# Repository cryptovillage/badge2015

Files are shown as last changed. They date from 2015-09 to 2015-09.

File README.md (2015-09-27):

# badge2015
Hardware, firmware, and documentation for the 2015 Crypto and Privacy Village Badge

# FAQs

Q: How do I build the firmware?

A: The firmware is built with Energia, an Arduino port for the MSP430. You will need to add
support for the MSP430G2955 to Energia. We used this "support pack:"
http://spirilis.net/junk/msp430/energia/g2955/energia13_g2955_spirilis_support.zip

Q: How are the flags/easter eggs hashed? 

A: Flags and easter eggs are hashed with a custom algorithm inspired by crypt(3). It uses about 3000
rounds of XXTEA cipher. The second-to-last round of XXTEA produces a key that is used to decrypt the
easter egg strings, which are themselves encrypted with XXTEA.

Q: Why 3000 rounds?

A: The number of rounds was chosen by observing how long the badge would take to validate a flag.
3000 rounds caused flag validation to take an amount of time just felt right. 3000 rounds also
makes brute-forcing the hashes infeasible, especially over a weekend. Remember, this hashing scheme
was not intended to be unbreakable -- just unbreakable over the weekend of DEF CON.

Q: Why are the genflag/genegg tools broken?

A: You need to compile them with -m32. The XXTEA code assumes 32-bit longs, but GCC uses 64-bit longs
on 64-bit architectures. Yes, I am aware this is easy to fix. Pull requests accepted!

Q: What's the story behind "Tetris mode?"

A: I wanted one of the challenges to involve a sidechannel attack. Unfortunately, if we wanted to
hide a secret on the MSP430, we'd have to blow the JTAG fuse, and we wanted to keep these badges as
hackable as possible. I also wanted to make a sidechannel challenge that did not require special
hardware. We were also somewhat constrained because the hardware had already been manufactured. I
knew that AM radios could pick up electromagnetic interference from digital devices, and everyone
at DEF CON probably had an AM radio in their hotel room. After a cursory search of the Internet, I 
found that someone had already implemented an AM transmitter by blinking an LED with an Atmel AVR!
We adapted their sample code, which played the "Tetris theme song."

Q: What's the unpopulated IC footprint on the badge for?

A: That is for a digital compass which was intended to be incorporated into the badge but dropped at
the last minute.

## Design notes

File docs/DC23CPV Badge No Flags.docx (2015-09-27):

# (U) DEF CON 23 Crypto And Privacy Village Badge Design Document

~~(U//FOUO)~~ This document contains the firmware specifications for the DEF CON 23 Crypto and Privacy Village Badge, including all behavior, flags, and easter eggs.

# (U) Testing

~~(U//FOUO)~~ When the badge is first powered up, it enters a self-test mode. All LEDs and segments on the display are lit for one second. After that, the badge cycles through all LEDs and segments individually. Pressing the left or right buttons cause an “L” or “R” to be displayed. Pressing both buttons simultaneously exits the self-test mode. The badge will not re-enter self-test mode without clearing the NVM.

# (U) Operation

## (U) Display Mode

~~(U//FOUO)~~ The badge is normally in “display mode,” which cycles through the words “DEFCON23,” “CRYPTO,” “AND,” “PRIVACY,” “VILLAGE.” There are 12 challenges to complete. The green LEDs corresponding to each challenge pulsate to indicate which challenges have been completed.

~~(C//REL)~~ If the Matrix easter egg is enabled, then the cycling of strings is slower. Part of the cycle time is used to resolve randomized characters to their actual characters. The random characters and resolution positions are generated by a 16-bit maximal LFSR. Any subset of the seven segments can be lit.

~~(C//REL)~~ If the LED1 easter egg is enabled, then the green LEDs randomly light every 250 milliseconds as chosen by a 16-bit maximal LFSR.

~~(C//REL)~~ If the LED2 easter egg is enabled, then the green LEDs perform a “walk.” LEDs start lighting up clockwise from the “walk” position until reaching the “walk” position, at which point the LEDs are extinguished clockwise until reaching the “walk” position again. The “walk” position then advances.

~~(C//REL)~~ If the Count easter egg is enabled, then the green LEDs count in binary, with the 12 o’clock position being the least-significant bit, and the 11 o’clock position being the most-significant bit.

~~(C//REL)~~ If the Pong easter egg is enabled, then the green LEDs perform a “pong” display. One LED advances slowly clockwise. Another LED advances either counter-clockwise or clockwise until it hits the slowly-advancing LED, at which point it reverses direction.

~~(C//REL)~~ If any easter egg messages are enabled, they will scroll after the “DEFCON23 CRYPTO AND PRIVACY VILLAGE” message is displayed.

~~(C//REL)~~ The preceding easter eggs are temporary and do not persist across power-cycles.

~~(C//REL)~~ If the EFF donor easter egg is activated, then users may cycle through a subset of the easter eggs (LED1, LED2, Pong, Matrix, and an “I fight for the users” message) by pressing the up button. The EFF donor flag persists across power-cycles but the easter egg enabled does not.

~~(TS//REL)~~ If all challenges are completed, the green LEDs randomly light every 50 milliseconds.

~~(TS//REL)~~ By pressing Up Up Down Down Up Down Up Down in “display mode,” the flag display mode can be entered which can be used to verify flags submitted.

## (U) Flag Entry Mode

~~(U//FOUO)~~ To enter the solution to a challenge (hereinafter referred to as a “flag”), press the right button in display mode. The green LEDs extinguish and the main display starts blinking an underscore to indicate that it is ready to accept an entry. Pressing the up and down buttons cycle through the characters of the current position, which blinks. An underscore indicates a space. Holding the down button for one second advances the character position. Advancing from the last position submits the flag for verification. Holding the up button for one second performs a backspace. Backspacing from the first position returns to “display mode.” Flags may also be submitted by pressing both buttons simultaneously. Empty spaces at the end of a flag will be converted to NULs before flag validation.

~~(U//FOUO)~~ Upon entry of a correct flag, the display will fade up the word “SUCCESS” and the corresponding green LEDs begins to pulsate. An animation of the other LEDs accents the newly lit LED. After five seconds, the badge reverts to “display mode.”

~~(C//REL)~~ Entry of any easter egg will activate that particular easter egg. Easter eggs are discussed below.

~~(C//REL)~~ Entry of a flag that is not a valid flag or easter egg will cause “LOL FAIL” to display for five seconds before reverting to “display mode.”

~~(S//REL)~~ Cycling through characters backwards through “A” will reveal 12 more non-unique characters, which light a corresponding green LED. These characters are used in a puzzle.

## ~~(~~~~S//REL)~~ Baudot/SSE Mode

~~(S//REL)~~ Upon entry to the Baudot mode, “LOOK IN TO MY EYES” scrolls across the display. Two sets of five green LEDs light in sequence to spell out characters using Baudot encoding. LEDs on the left side of the badge are the first, third, etc. characters, and LEDs on the right side of the badge are the second, fourth, etc. characters. Bits are ordered most-significant to least-significant from 11 o’clock to 1 o’clock.

## ~~(~~~~S//REL)~~ Tetris/RF mode

~~(S//REL)~~ Upon entry to Tetris mode, all LEDs and segments are extinguished except for the 3 o’clock LED, which stays lit. The 3 o’clock LED is modulated to provide music (commonly known as the “Tetris theme”) broadcast at 550 kHz using AM. At the end of this song, a message in Morse code is played at 15 WPM.

## ~~(C//REL)~~ Party/Rager mode

~~(C//REL)~~ After entering these easter eggs, the display scrolls “Are you sure?” followed by a display of “Y N.” If the left button is pressed (corresponding to Y), party mode is entered. If the right button is pressed, the badge goes back to “display mode.” If party mode is entered, a bit is set in NVM recording this fact. The duration of party mode (15 minutes for “party”, 60 minutes for “rager”) is also stored in NVM as a bit vector.

~~(C//REL)~~ In party mode, the green LEDs blink at 128 BPM. The LEDs are on for the duration of a sixteenth note at 128 BPM. The display scrolls “PARTY” back and forth, moving the position at 128 WPM. Party mode cannot be stopped. Every 60 seconds, the party duration counter is decremented in NVM. If the party duration reaches 0, the party bit in NVM is reset and the badge goes back to “display mode.”

## ~~(C//REL)~~ The “fuck” lockout

~~(C//REL)~~ If the word “fuck” is submitted as a flag, a bit is set in NVM indicating this fact. Display mode will not show anything but a series of dashes when this flag is set. Additionally, flag entry mode will not accept any flag except “sorry.” Other valid flags or easter eggs will cause “LOL FAIL” to be displayed. If “sorry” is submitted, the badge says “please don’t do it again,” clears the bit in NVM, and returns to display mode.

## ~~(C//REL)~~ Bullet time

~~(C//REL)~~ If the bullet time easter egg is entered, the display and LEDs are refreshed at a much slower interval (every 20 milliseconds).

## ~~(C//REL)~~ Resetting NVM

~~(C//REL)~~ The NVM can be completely erased by submitting “factoryr.” This will restore the self-test mode on the next power-cycle and clear all flags and other bits set.

# ~~(U//FOUO)~~ Flags

~~(S//REL)~~ Flags are “hashed” by through repeated encryptions by the XXTEA algorithm using the flag as the key. The initial input to XXTEA is 0x0000000000000001, and subsequent inputs are the outputs of previous iterations. Flags are hashed 3001 times. The output of the 3000th round is used as an XXTEA decryption key for easter egg messages.

~~(U//FOUO)~~ Flag list

~~(TS//REL)~~

12 o’clock | N
1 o’clock | NNE
2 o’clock | ENE
3 o’clock | E
4 o’clock | ESE
5 o’clock | SSE
6 o’clock | S
7 o’clock | SSW
8 o’clock | WSW
9 o’clock | W
10 o’clock | WNW
11 o’clock | NNW

~~(S//REL)~~ Puzzle mode enablers

SSE | SSE | Enters Baudot mode
NNW | TETRIS | Enters Tetris mode

# ~~(C//REL)~~ Easter Eggs

~~(C~~~~//REL)~~ Messages

HACK | “Drink all the booze hack all the things”
1337 | “got root”
CYBER | “GOVERNMENT MEDIA NOOB DRINK”
CYBER2 | “CYBER CYBER CYBER CYBER CYBER CYBER”
WBM | “FDHNER CRT VA N EBHAQ JBEYQ”
SUPERSAT | “HACKER EXTRAORDINARE”
JORGE | “The creator or dad”
GIBSON | “Hack the planet crash and burn”
ACIDBURN | “crash and burn”
ZEROCOOL | “mess with the best die like the rest”
JEFFMOSS | “ICANN PARTY”
TRAVIS | “FUCK YOU NEIGHBOR”
OSSMANN | “such radio much sniff wow”
GMARK | “don’t fuck it up”
NSA | “I C U P”
GOON | “HI PRIEST”
BEER | “take a drink”
HAD | “hackaday”
NINJA | “NINJA PARTY”
NEON | “LIZARD MOHAWKS FOR LIFE”
DIFFIE | “I love discrete logs”
HELLMAN | “Watch out for Mallory”
1o57 | “e ahzojr nrjx qbr Amfx, qyeyxs ume xev myfpxpnxffr”
DEFCON | “canceled next year”
DEFCOIN | “cash rules everything around me”
ALICE | “bit ly alicenbob”
BOB | “Alice is sending her message to Bob Protecting that transmission is crypto’s job”
EVE | “Eve is jealous of Alice”
ROT13 | “So secure”
OPENSSL | “Open Season”
EFF | “Fighting for the users”
DARTHNULL | YGcpeevgCIKgfnMwefXzvGUHe3BgQKdxkMFeappqmVT0cNOkvGY6ehfo”
WARGAMES | “Shall we play a game”
SNEAKERS | “The world isn’t by weapons anymore or energy or money its run by little ones and zeros little bits of data Its all just electrons.”
SETEC | “Too many secrets marty”
LOTR | “Keep it secret keep it safe”
SCORPION | “250 years of bullshit er human thought every 90 minutes”

~~(C//REL)~~ Other easter eggs

MATRIX | Enables Matrix Mode
FUCK | Enables the “fuck” lockout
LED1 | Enables LED1 easter egg
LED2 | Enables LED2 easter egg
PONG | Enables PONG easter egg
COUNT | Enables Count easter egg
PARTY | Enables 15 minute party mode
RAGER | Enables 60 minute party mode
SORRY | Removes the “fuck” lockout
3FFD0N0R | Says “thank you for supporting the EFF” and set the EFF supporter bit
OVERCLOK | Sets ledMaxBrightness to 0xff (already 0xff on final firmware)
BULLETYM | Enables bullet time easter egg
FACTORYR | Performs a full erase of the NVM

[Type text][Type text][Type text]

~~TOP SECRET//DEFCON//REL TO 4EYES~~

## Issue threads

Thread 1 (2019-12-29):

re-programming

gigawatts, 2019-12-29:
I was looking to explore re-purposing / programming this badge, and I am looking for a pin-out for the programming header on the badge, along with some tips on a procedure.

Is it using this pinout? https://www.olimex.com/Products/MSP430/_resources/msp430-jtag.gif

I saw the "CONN_01x14 / P1" connector in the schematic PDF, but it only labels 4 pins. Are the rest not connected to the MSP430?

Do you have some notes on a process to re-flash this? My only other MSP experience is on a Stellaris LaunchPad (with Energia), but that was easily re-programmed with just USB. I have a few other programmers available, including a buspirate and Black Magic Probe clone.

Any hints would be appreciated!

supersat, 2019-12-29:
You are correct that only 4 pins on the programming header are connected to the MSP430. We debugged and programmed them using TI's Spy-Bi-Wire protocol instead of JTAG, which only requires those four pins.

The firmware was originally developed with a MSP-EXP430G2 LaunchPad, although the production badges have a larger microcontroller (MSP430G2955 vs MSP430G2744) that is not supported by it. Apparently newer LaunchPads might support it?

gigawatts, 2019-12-30:
Giving it a shot with my Stellaris LM4F120 (removing the jumper that powers the onboard micro.

Next issue, I downloaded the support pack you linked to, and based on its name, downloaded the old Energia 0101E0013 version, selected the "Spirilis' G2955 LaunchPad" board option, but every upload attempt just errors with "No unused FET found." What version of Energia did you use with that support pack?

I'm pretty sure I have all the right drivers installed, as I can upload sketches to the onboard lm4f120 micro just fine from Energia (selecting the lm4f120 board, of course).

gigawatts, 2020-01-07:
I gave up on the Stellaris, pretty sure it does not support SBW. I picked up a cheap LaunchPad MSP-EXP430G2. I was able to program it's onboard G2553 with Energia v13 without any issues. I removed the jumpers, then connected GND, VCC, RST, and TEST over to the badge.

Attempting to upload (after picking Board "Spirilis' G2955 LaunchPad"), I just get this error now:
```
tilib: MSP430_OpenDevice: Could not find device (or device not supported) (error = 4)
tilib: device initialization failed
```

Any ideas?

supersat, 2020-01-07:
The MSP-EXP430G2 explicitly does not support the G2955 (see my comment above). However, if you were to remove the G2955 and replace it with a G2744, it would be pin-compatible and work just fine.

That being said, it's probably easier to find a compatible programmer.

gigawatts, 2020-01-07:
Doh, then I misunderstood your previous statement about chip support. Which LaunchPad or programmer will work, without spending too much?

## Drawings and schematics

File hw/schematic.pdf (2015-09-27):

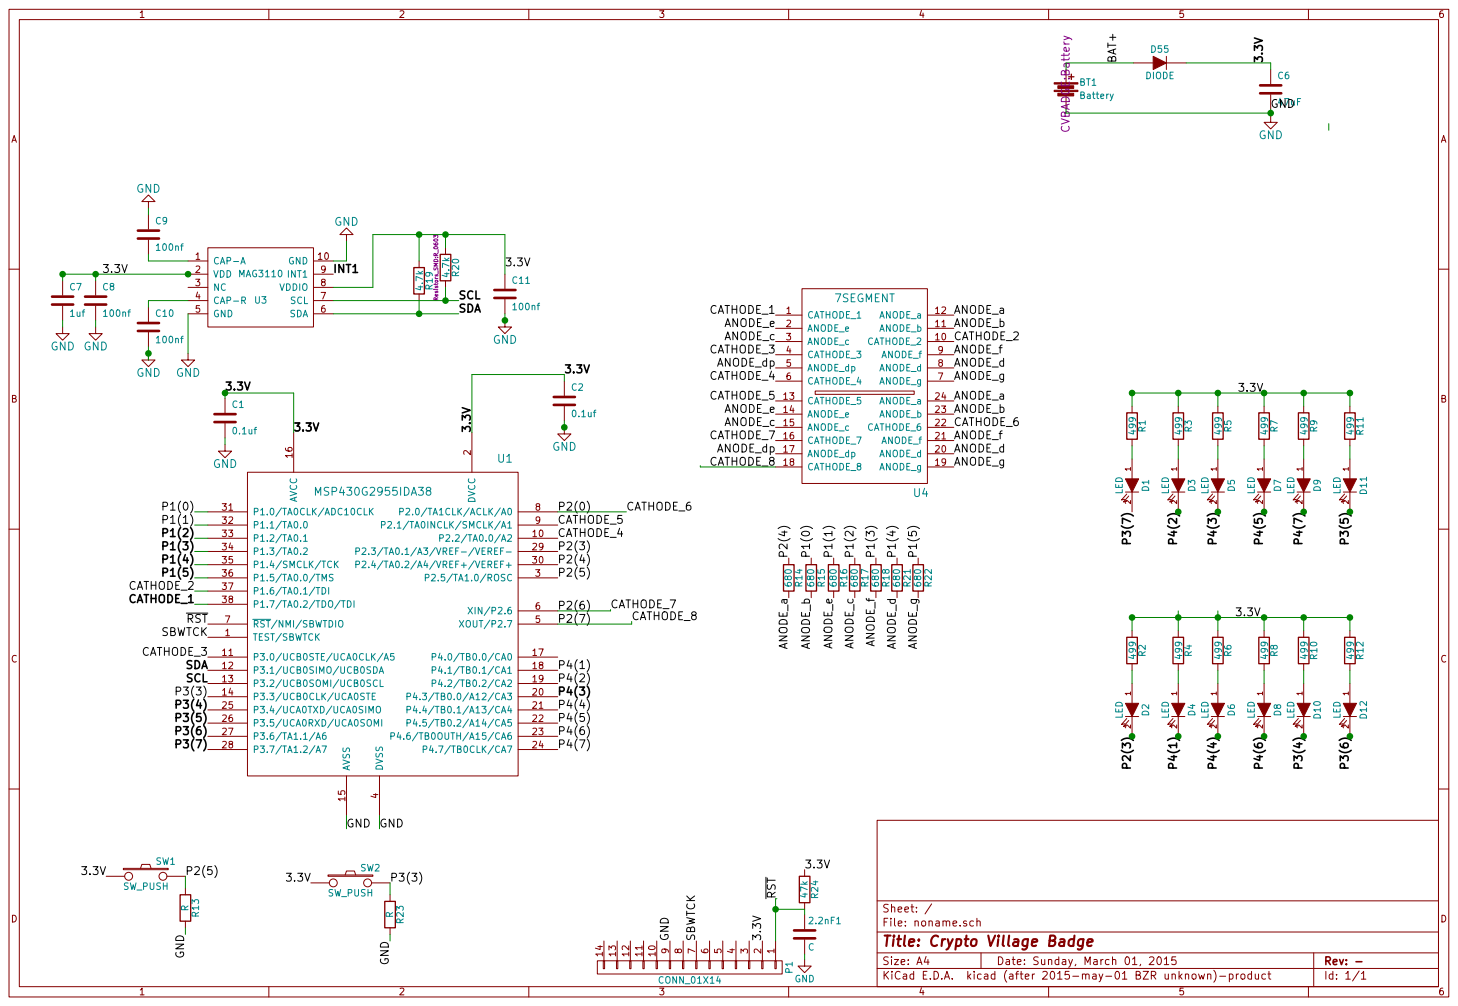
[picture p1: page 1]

Add in USB power? Remember to enable power off of USB as well C1

4 XOUT/P2.7 5 XIN/P2.6 6 RST/NMI/SBWTDIO 7 P2.0/TA1CLK/ACLK/A0 8 P2.1/TA0INCLK/SMCLK/A1 9 P2.2/TA0.0/A2 10 P4.3/TB0.0/A12/CA3 20 P2.4/TA0.2/A4/VREF+/VEREF+ 30 P3.0/UCB0STE/UCA0CLK/A5 11 P4.4/TB0.1/A13/CA4 21 P1.0/TA0CLK/ADC10CLK 31 P3.1/UCB0SIMO/UCB0SDA 12 P4.5/TB0.2/A14/CA5 22 P1.1/TA0.0 32 P3.2/UCB0SOMI/UCB0SCL 13 P4.6/TB0OUTH/A15/CA6 23 P1.2/TA0.1 33 P3.3/UCB0CLK/UCA0STE 14 P4.7/TB0CLK/CA7 24 P1.3/TA0.2 34 AVSS 15 P3.4/UCA0TXD/UCA0SIMO 25 P1.4/SMCLK/TCK 35 AVCC 16 P3.5/UCA0RXD/UCA0SOMI 26 P1.5/TA0.0/TMS 36 P4.0/TB0.0/CA0 17 P3.6/TA1.1/A6 27 P1.6/TA0.1/TDI 37 P4.1/TB0.1/CA1 18 P3.7/TA1.2/A7 28 P1.7/TA0.2/TDO/TDI 38 P4.2/TB0.2/CA2 19 P2.3/TA0.1/A3/VREF/VEREF 29 U1 MSP430G2955IDA38

File: noname.sch Sheet: /
Id: 1/1 Title: Crypto Village Badge

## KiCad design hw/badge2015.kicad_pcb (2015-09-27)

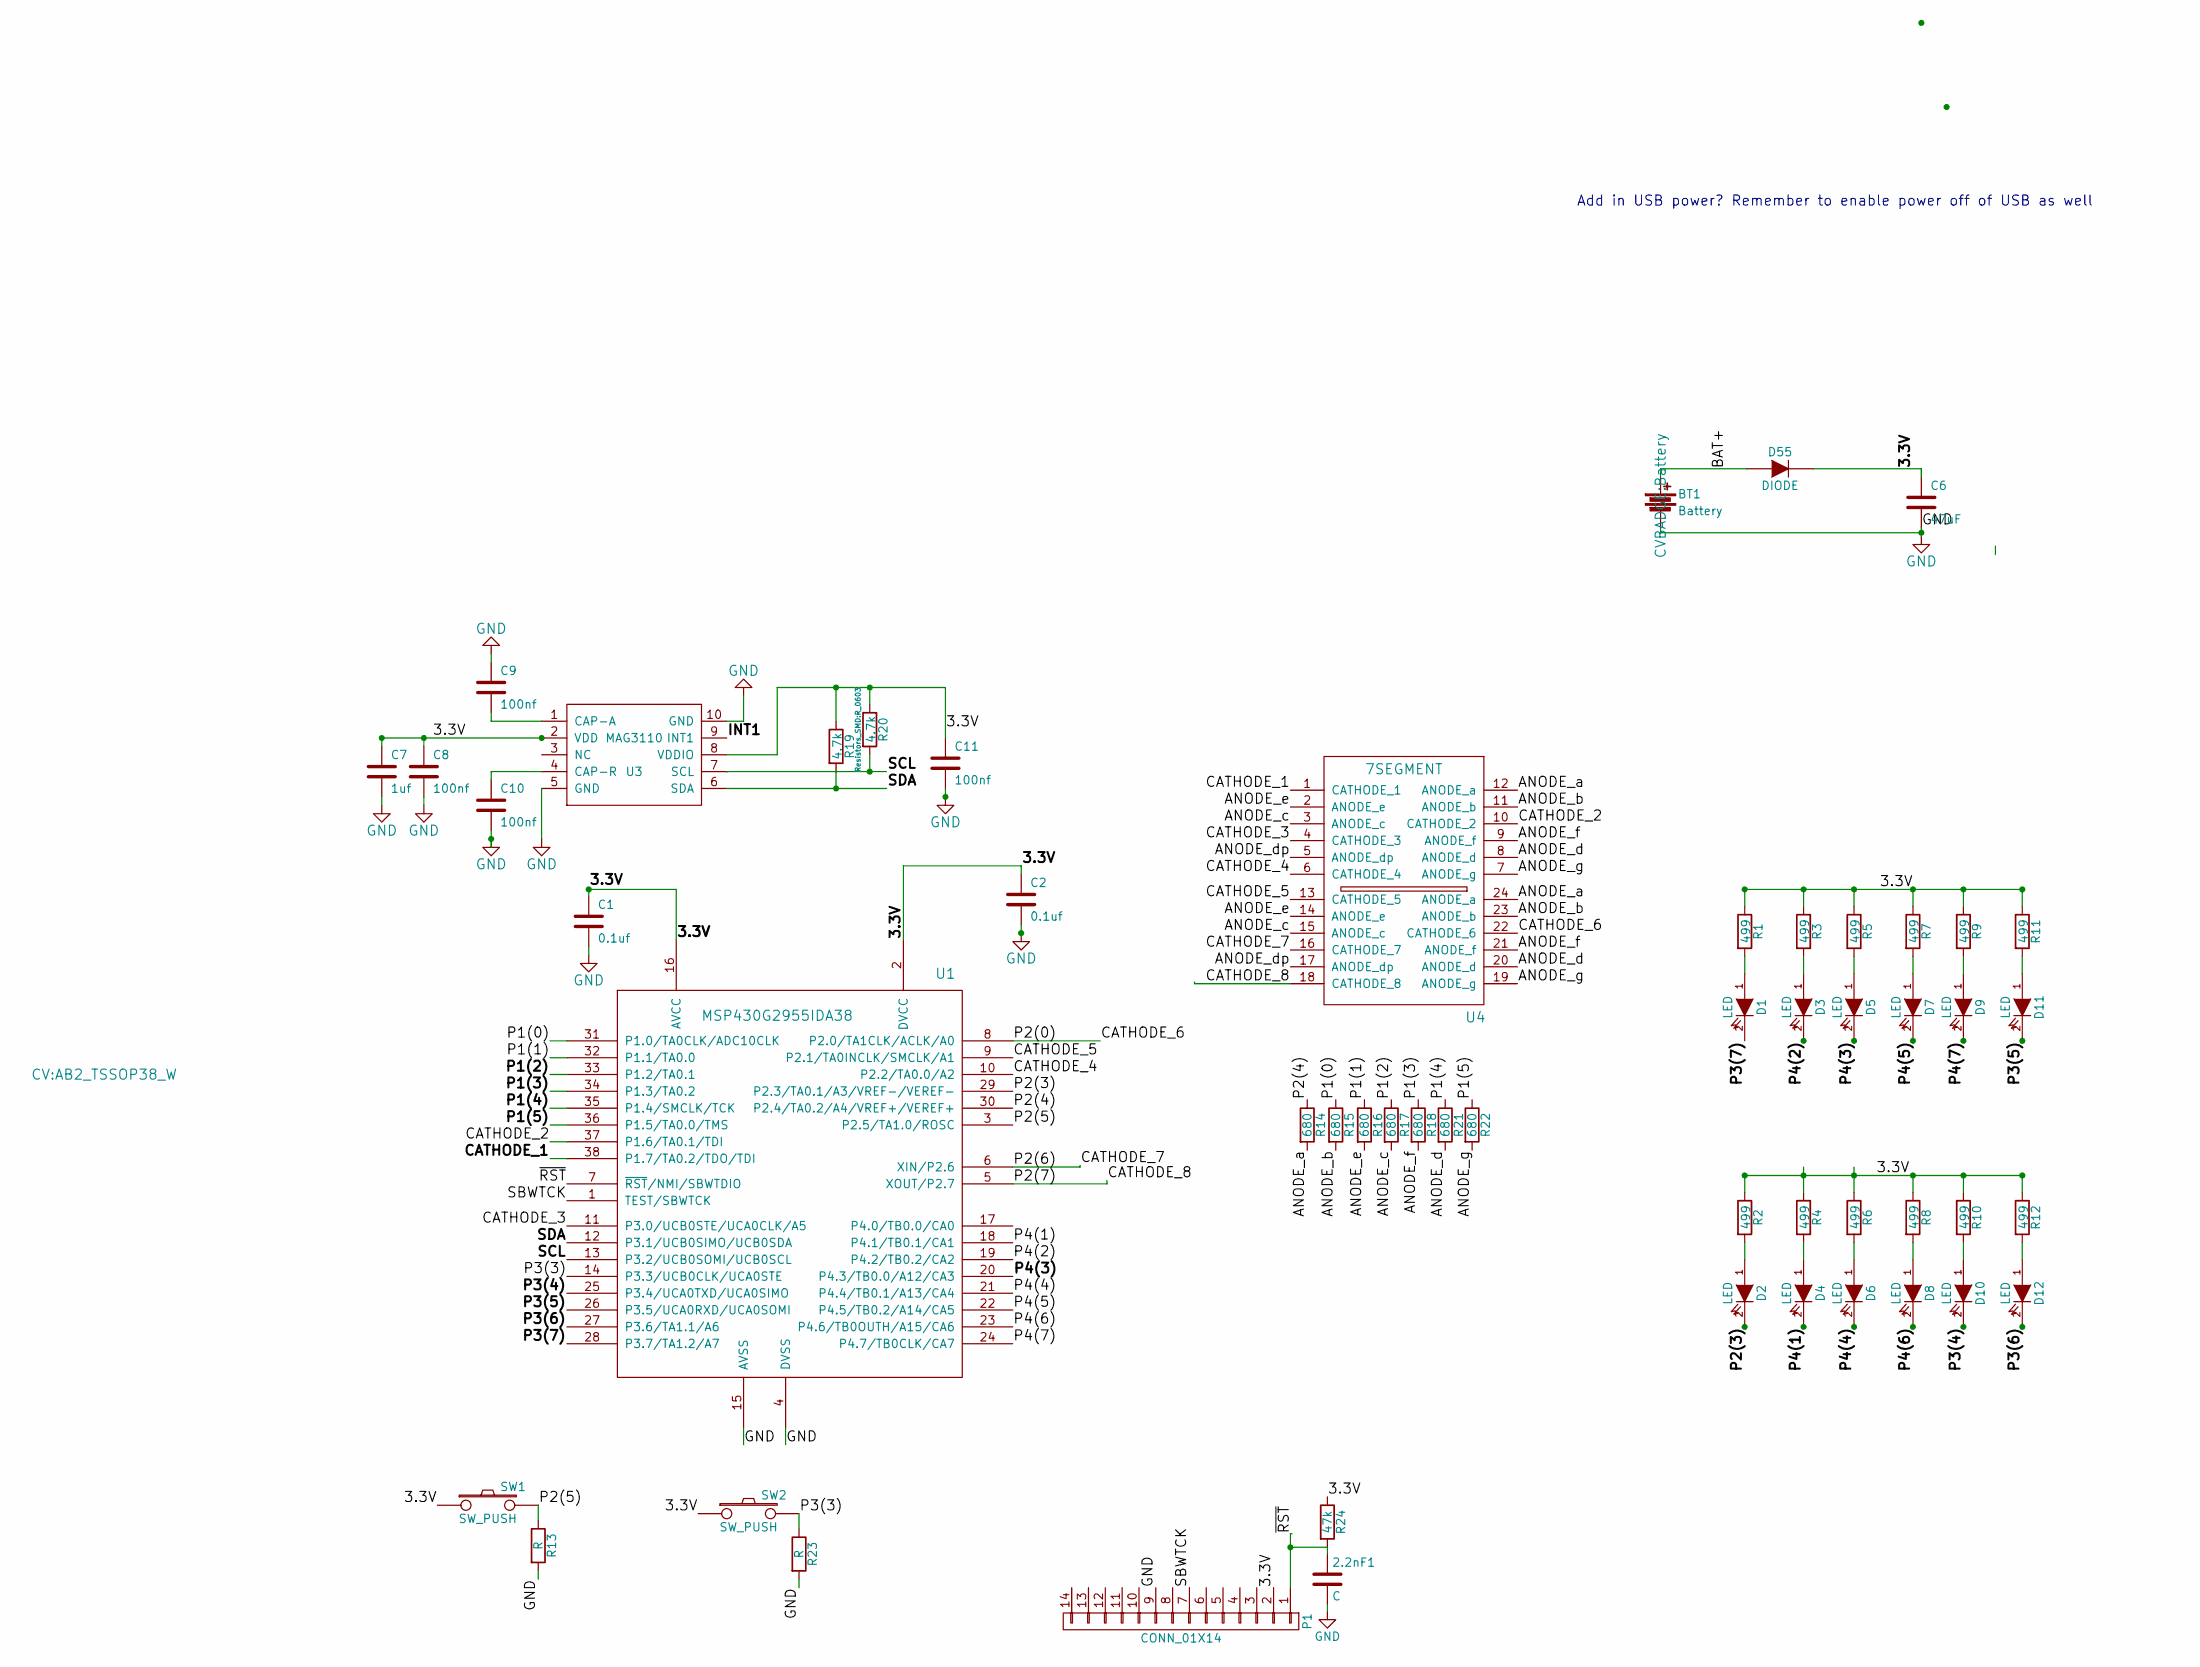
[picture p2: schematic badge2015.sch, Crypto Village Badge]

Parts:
2.2nF1: C; C_0603
BT1: Battery
C1, C2: 0.1uf; C_0603
C6: 47uF; C_1206
C7: 1uf; C_0603
C8, C9, C10, C11: 100nf; C_0603
D1, D2, D3, D4, D5, D6, D7, D8, D9, D10, D11, D12: LED; LED-0603
D55: DIODE; LED-0603
P1: CONN_01X14; Pin_Header_Straight_2x07
R1, R2, R3, R4, R5, R6, R7, R8, R9, R10, R11, R12: 499; R_0603
R13, R23: R; R_0603
R14, R15, R16, R17, R18, R21, R22: 680; R_0603
R19, R20: 4.7k; R_0603
R24: 47k; R_0603
SW1, SW2: SW_PUSH; push_btn
U1: MSP430G2955IDA38; AB2_TSSOP38_W
U3: MAG3110; MAG3110_10VFDFN
U4: 7SEGMENT; DIP-24__300_ELL

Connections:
/3.3V: C1.1, C2.1, C6.1, C7.1, C8.1, C11.1, D55.2 (K), P1.2, R1.1, R2.1, R3.1, R4.1, R5.1, R6.1, R7.1, R8.1, R9.1, R10.1, R11.1, R12.1, R19.1, R20.1, R24.1, SW1.1, SW2.1, U1.2 (DVCC), U1.16 (AVCC), U3.2 (VDD), U3.8 (VDDIO); also elsewhere on the board
/ANODE_a: R14.2, U4.12 (ANODE_a), U4.24 (ANODE_a)
/ANODE_b: R15.2, U4.11 (ANODE_b), U4.23 (ANODE_b)
/ANODE_c: R17.2, U4.3 (ANODE_c), U4.15 (ANODE_c)
/ANODE_d: R21.2, U4.8 (ANODE_d), U4.20 (ANODE_d)
/ANODE_dp: U4.5 (ANODE_dp), U4.17 (ANODE_dp)
/ANODE_e: R16.2, U4.2 (ANODE_e), U4.14 (ANODE_e)
/ANODE_f: R18.2, U4.9 (ANODE_f), U4.21 (ANODE_f)
/ANODE_g: R22.2, U4.7 (ANODE_g), U4.19 (ANODE_g)
/BAT+: BT1.1, D55.1 (A)
/CATHODE_1: U1.38 (P1.7/TA0.2/TDO/TDI), U4.1 (CATHODE_1)
/CATHODE_2: U1.37 (P1.6/TA0.1/TDI), U4.10 (CATHODE_2)
/CATHODE_3: U1.11 (P3.0/UCB0STE/UCA0CLK/A5), U4.4 (CATHODE_3)
/CATHODE_4: U1.10 (P2.2/TA0.0/A2), U4.6 (CATHODE_4)
/CATHODE_5: U1.9 (P2.1/TA0INCLK/SMCLK/A1), U4.13 (CATHODE_5)
/CATHODE_6: U1.8 (P2.0/TA1CLK/ACLK/A0), U4.22 (CATHODE_6)
/CATHODE_7: U1.6 (XIN/P2.6), U4.16 (CATHODE_7)
/CATHODE_8: U1.5 (XOUT/P2.7), U4.18 (CATHODE_8)
/P1(0): R15.1, U1.31 (P1.0/TA0CLK/ADC10CLK)
/P1(1): R16.1, U1.32 (P1.1/TA0.0)
/P1(2): R17.1, U1.33 (P1.2/TA0.1)
/P1(3): R18.1, U1.34 (P1.3/TA0.2)
/P1(4): R21.1, U1.35 (P1.4/SMCLK/TCK)
/P1(5): R22.1, U1.36 (P1.5/TA0.0/TMS)
/P2(3): D2.2 (K), U1.29 (P2.3/TA0.1/A3/VREF−/VEREF−)
/P2(4): R14.1, U1.30 (P2.4/TA0.2/A4/VREF+/VEREF+)
/P2(5): R13.1, SW1.2, U1.3 (P2.5/TA1.0/ROSC)
/P3(3): R23.1, SW2.2, U1.14 (P3.3/UCB0CLK/UCA0STE)
/P3(4): D10.2 (K), U1.25 (P3.4/UCA0TXD/UCA0SIMO)
/P3(5): D11.2 (K), U1.26 (P3.5/UCA0RXD/UCA0SOMI)
/P3(6): D12.2 (K), U1.27 (P3.6/TA1.1/A6)
/P3(7): D1.2 (K), U1.28 (P3.7/TA1.2/A7)
/P4(1): D4.2 (K), U1.18 (P4.1/TB0.1/CA1)
/P4(2): D3.2 (K), U1.19 (P4.2/TB0.2/CA2)
/P4(3): D5.2 (K), U1.20 (P4.3/TB0.0/A12/CA3)
/P4(4): D6.2 (K), U1.21 (P4.4/TB0.1/A13/CA4)
/P4(5): D7.2 (K), U1.22 (P4.5/TB0.2/A14/CA5)
/P4(6): D8.2 (K), U1.23 (P4.6/TB0OUTH/A15/CA6)
/P4(7): D9.2 (K), U1.24 (P4.7/TB0CLK/CA7)
/SBWTCK: P1.7, U1.1 (TEST/SBWTCK)
/SCL: R20.2, U1.13 (P3.2/UCB0SOMI/UCB0SCL), U3.7 (SCL); also elsewhere on the board
/SDA: R19.2, U1.12 (P3.1/UCB0SIMO/UCB0SDA), U3.6 (SDA); also elsewhere on the board
/~RST: 2.2nF1.1, P1.1, R24.2, U1.7 (~RST~/NMI/SBWTDIO)
GND: 2.2nF1.2, BT1.2, C1.2, C2.2, C6.2, C7.2, C8.2, C9.1, C10.2, C11.2, P1.9, R13.2, R23.2, U1.4 (DVSS), U1.15 (AVSS), U3.5 (GND), U3.10 (GND); also elsewhere on the board
unnamed 45: C9.2, U3.1 (CAP-A); also elsewhere on the board
unnamed 46: C10.1, U3.4 (CAP-R); also elsewhere on the board
unnamed: D1.1 (A), R1.2
unnamed: D2.1 (A), R2.2
unnamed: D3.1 (A), R3.2
unnamed: D4.1 (A), R4.2
unnamed: D5.1 (A), R5.2
unnamed: D6.1 (A), R6.2
unnamed: D7.1 (A), R7.2
unnamed: D8.1 (A), R8.2
unnamed: D9.1 (A), R9.2
unnamed: D10.1 (A), R10.2
unnamed: D11.1 (A), R11.2
unnamed: D12.1 (A), R12.2

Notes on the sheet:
Add in USB power? Remember to enable power off of USB as well

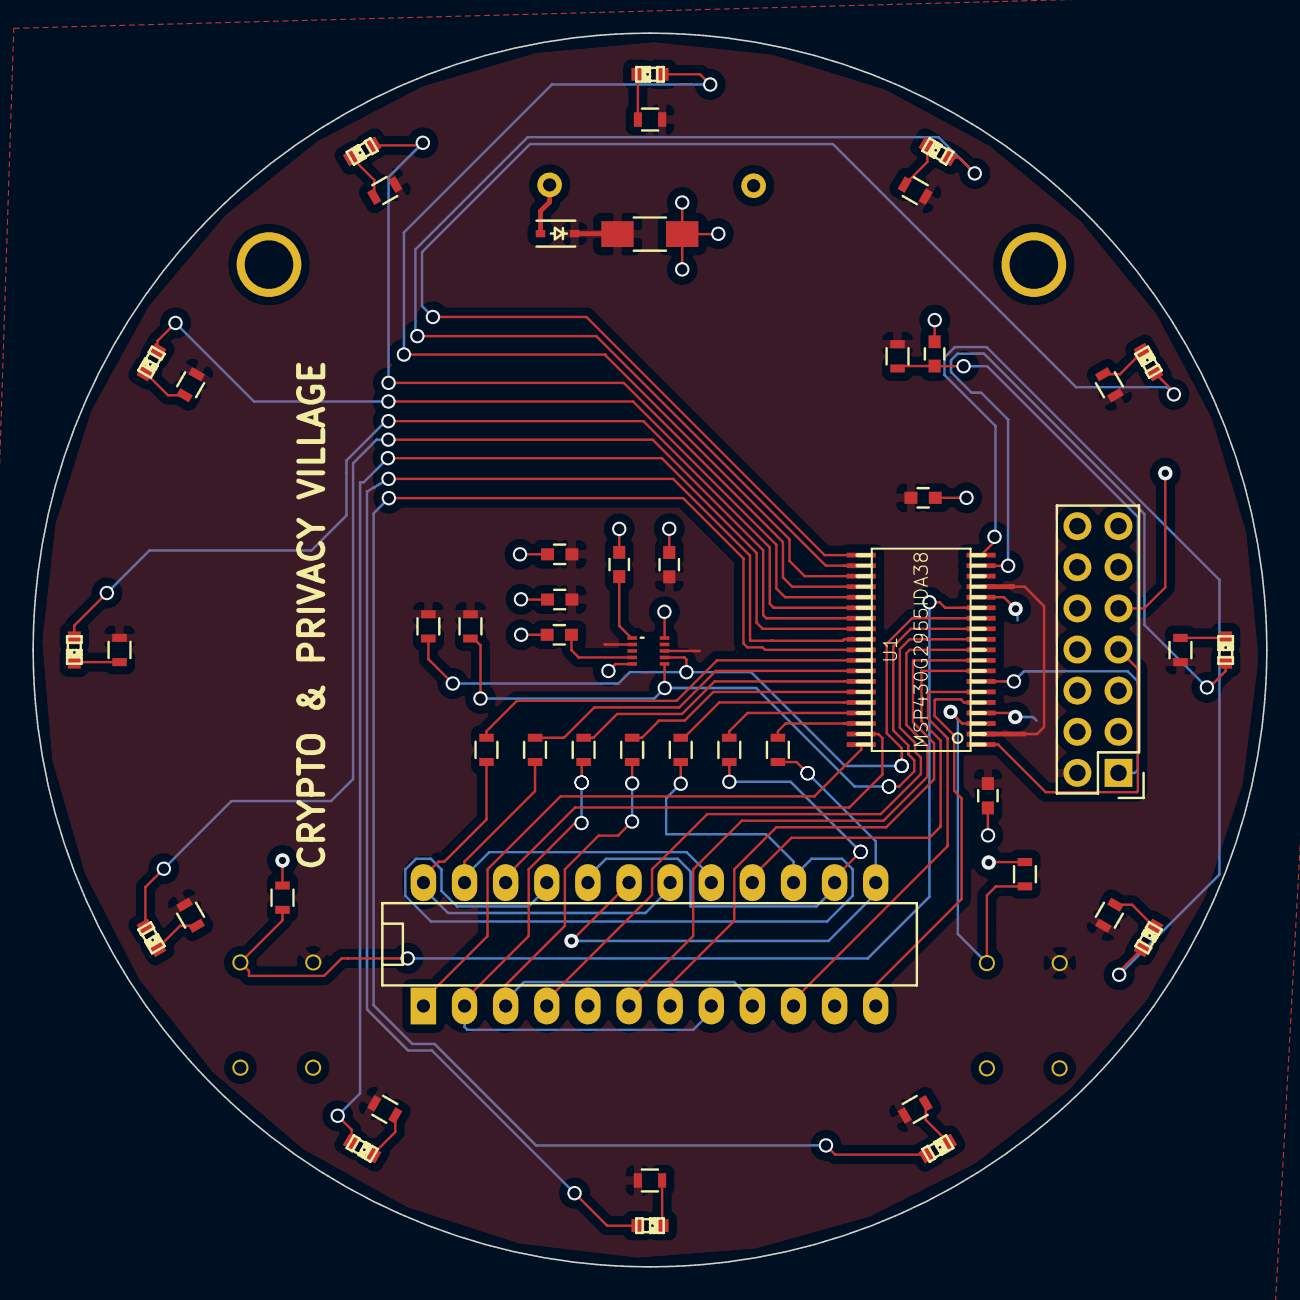
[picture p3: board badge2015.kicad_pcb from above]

Board: 2 copper layers, 76.2 x 76.2 mm, 55 parts (1 on the bottom side), 58 nets.

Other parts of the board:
MAG: MAG3110_10VFDFN
hole_l: hole
hole_r: hole_r; hole

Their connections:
/3.3V: MAG.2, MAG.8; also elsewhere on the board
/SCL: MAG.7; also elsewhere on the board
/SDA: MAG.6; also elsewhere on the board
GND: MAG.5, MAG.10; also elsewhere on the board
unnamed 45: MAG.1; also elsewhere on the board
unnamed 46: MAG.4; also elsewhere on the board

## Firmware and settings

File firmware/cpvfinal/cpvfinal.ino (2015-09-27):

//#include <msp430g2955.h>

struct badgeNVM_t {
  char flags[12][8];
  char padding[28];
  //byte flagHashes[12][16];
  unsigned short challengesSolved;
  byte selfTestEnabled;
  byte padding2[1];
  // Next segment
  byte partyTime[8];
  byte modeFlags;
};

badgeNVM_t *nvm = (badgeNVM_t *)0x1000;

#define IGNORE_LEFT_UP  (1 << 7)
#define IGNORE_RIGHT_UP (1 << 6)
#define LEFT_PRESSED    (1 << 5)
#define RIGHT_PRESSED   (1 << 4)
#define LEFT_UP         (1 << 3)
#define RIGHT_UP        (1 << 2)
#define LEFT_DOWN       (1 << 1)
#define RIGHT_DOWN      (1 << 0)

byte tempModeFlag = 0;
byte buttonStatus = 0;
byte maxLEDBrightness = 0xff;
byte curString = 0;

enum badgeState_t {
  SELF_TEST_MODE,
  DISPLAY_MODE,
  FLAG_ENTRY_MODE,
  FLAG_OBTAINED_MODE,
  FLAG_FAIL_MODE,
  SCROLL_MODE,
  RF_MODE,
  PARTY_CONFIRM_MODE,
  PARTY_MODE,
  SSE_MODE,
  SHOW_FLAG_MODE,
};

badgeState_t badgeState;

#define MODE_FLAG_PARTY         (1 << 0)
#define MODE_FLAG_FUCK          (1 << 1)
#define MODE_FLAG_EFF_SUPPORTER (1 << 2)

#define TEMP_MODE_FLAG_MATRIX        (1 << 2)
#define TEMP_MODE_FLAG_BULLET_TIME   (1 << 3)
#define TEMP_MODE_FLAG_EGG_MSG       (1 << 4)
#define TEMP_MODE_FLAG_LED1          (1 << 5)
#define TEMP_MODE_FLAG_LED2          (2 << 5)
#define TEMP_MODE_FLAG_COUNT         (3 << 5)
#define TEMP_MODE_FLAG_PONG          (4 << 5)

void unlockFlash()
{
  disableWatchDog();
  FCTL3 = FWKEY;
  FCTL2 = FWKEY + FSSEL1+((F_CPU/400000L) & 63);
  FCTL1 = FWKEY | WRT;
}
 
void lockFlash()
{
  FCTL1 = FWKEY;
  FCTL3 = FWKEY | LOCK;
  enableWatchDog();
}

void eraseFlash()
{
  disableWatchDog();
  FCTL3 = FWKEY;
  FCTL1 = FWKEY + ERASE;
  nvm->flags[0][0] = 0xff;
  while (FCTL3 & BUSY);
  FCTL1 = FWKEY + ERASE;
  nvm->flags[8][0] = 0xff;
  while (FCTL3 & BUSY);
  FCTL1 = FWKEY + ERASE;
  nvm->partyTime[0] = 0xff;
  while (FCTL3 & BUSY);
  FCTL1 = FWKEY;
  FCTL3 = FWKEY | LOCK;
  enableWatchDog();
}

void erasePersistantModes()
{
  disableWatchDog();
  FCTL3 = FWKEY;
  FCTL1 = FWKEY + ERASE;
  nvm->partyTime[0] = 0xff;
  while (FCTL3 & BUSY);
  FCTL1 = FWKEY;
  FCTL3 = FWKEY | LOCK;
  enableWatchDog();
}

static const byte numCharTable[] = {
  0x5F, 0x05, 0x73, 0x75, 0x2D, 0x7C, 0x7E, 0x45,
  0x7F, 0x6D
}; 

static const byte alphaCharTable[] = {
  0x6F, 0x3E, 0x5a, 0x37, 0x7A, 0x6A, 0x5e, 0x2E,
  0x0A, 0x17, 0x6e, 0x1A, 0x46, 0x4f, 0x36, 0x6B,
  0x6D, 0x4b, 0x5C, 0x3a, 0x1f, 0x1d, 0x19, 0x2f,
  0x3D, 0x53
};

void setAnodes(char c)
{
  byte anodes = 0;
  
  if (c >= '0' && c <= '9') {
    anodes = numCharTable[c - '0'];
  } else if (c >= 'A' && c <= 'Z') {
    anodes = alphaCharTable[c - 'A'];
  } else if (c >= 'a' && c <= 'z') {
    anodes = alphaCharTable[c - 'a'];
  } else if (c & 0x80) {
    anodes = c & 0x7f;
  }
  
  P1OUT = (P1OUT & 0xc0) | (anodes & 0x3f);
  if (anodes & 0x40) {
    P2OUT |= (1 << 4);
  } else {
    P2OUT &= ~(1 << 4);
  }
}

char dispBuf[8]; // 7-segment display buffer
byte ledBuf[12]; // Ring of LEDs buffer
byte charPos = 0;
byte pwmCount = 0;
//byte ledPos = 0;

void refreshDisplay()
{
  byte ledPos;
  
  // Cathodes high, anodes low
  P1OUT = 0xc0;
  P2OUT = 0xff;
  P3OUT = 0xff;
  P4OUT = 0xff;

  setAnodes(dispBuf[charPos]);
  switch (charPos) {
  case 0:
    P1OUT &= ~(1 << 7);
    break;
  case 1:
    P1OUT &= ~(1 << 6);
    break;
  case 2:
    P3OUT &= ~(1 << 0);
    break;
  case 3:
    P2OUT &= ~(1 << 2);
    break;
  case 4:
    P2OUT &= ~(1 << 1);
    break;
  case 5:
    P2OUT &= ~(1 << 0);
    break;
  case 6:
    P2OUT &= ~(1 << 6);
    break;
  case 7:
    P2OUT &= ~(1 << 7);
    break;
  }
  
  // Increment charPos, mod 8
  charPos = (charPos + 1) & 0x7;

  for (ledPos = 0; ledPos < 12; ledPos++) {  
    if ((ledBuf[ledPos] >> 3) >= pwmCount && pwmCount) {
      switch(ledPos) {
      case 0:
        P4OUT &= ~(1 << 5);
        break;
      case 1:
        P4OUT &= ~(1 << 4);
        break;
      case 2:
        P4OUT &= ~(1 << 3);
        break;
      case 3:
        P4OUT &= ~(1 << 1);
        break;
      case 4:
        P4OUT &= ~(1 << 2);
        break;
      case 5:
        P2OUT &= ~(1 << 3);
        break;
      case 6:
        P3OUT &= ~(1 << 7);
        break;
      case 7:
        P3OUT &= ~(1 << 6);
        break;
      case 8:
        P3OUT &= ~(1 << 5);
        break;
      case 9:
        P3OUT &= ~(1 << 4);
        break;
      case 10:
        P4OUT &= ~(1 << 7);
        break;
      case 11:
        P4OUT &= ~(1 << 6);
        break;
      }
    }
  }
  
  pwmCount = (pwmCount + 1) & 0x1f;
  /*
  ledPos++;
  if (ledPos >= 12) {
    ledPos = 0;
  }
  */
}

void updateButtonStatus()
{
  static unsigned short leftButtonSR = 0;
  static unsigned short rightButtonSR = 0;
  
  leftButtonSR <<= 1;
  rightButtonSR <<= 1;
  if (P3IN & (1 << 3))
    leftButtonSR |= 1;
    //rightButtonSR |= 1;
  if (P2IN & (1 << 5))
    rightButtonSR |= 1;
    //leftButtonSR |= 1;
    
  buttonStatus &= ~(LEFT_UP | RIGHT_UP | LEFT_DOWN | RIGHT_DOWN);
  if (leftButtonSR == 0) {
    if (buttonStatus & LEFT_PRESSED) {
      if (!(buttonStatus & IGNORE_LEFT_UP))
        buttonStatus |= LEFT_UP;
      buttonStatus &= ~(IGNORE_LEFT_UP | LEFT_PRESSED);
    }
  } else if (leftButtonSR == 0xffff) {
    if (!(buttonStatus & LEFT_PRESSED)) {
      buttonStatus |= LEFT_PRESSED | LEFT_DOWN;
    }
  }
  
  if (rightButtonSR == 0) {
    if (buttonStatus & RIGHT_PRESSED) {
      if (!(buttonStatus & IGNORE_RIGHT_UP))
        buttonStatus |= RIGHT_UP;
      buttonStatus &= ~(IGNORE_RIGHT_UP | RIGHT_PRESSED);
    }
  } else if (rightButtonSR == 0xffff) {
    if (!(buttonStatus & RIGHT_PRESSED)) {
      buttonStatus |= RIGHT_PRESSED | RIGHT_DOWN;
    }
  }
}

unsigned short lfsr(int nIters)
{
  static unsigned short _lfsr = 1;
  
  while (nIters--) {
    unsigned short lsb = _lfsr & 1;
    _lfsr >>= 1;
    _lfsr ^= (-lsb) & 0xb400;
  }
  
  return _lfsr;
}

#define MX (z>>5^y<<2) + (y>>3^z<<4) ^ (sum^y) + (k[p&3^e]^z);
  
long btea(long* v, long n, long* k) {
  unsigned long z, y=v[0], sum=0, e, DELTA=0x9e3779b9;
  long p, q ;
  if (n > 1) {          /* Coding Part */
    z = v[n - 1];
    q = 6 + 52/n;
    while (q-- > 0) {
      sum += DELTA;
      e = (sum >> 2) & 3;
      for (p=0; p<n-1; p++) y = v[p+1], z = v[p] += MX;
      y = v[0];
      z = v[n-1] += MX;
    }
    return 0 ; 
  } else if (n < -1) {  /* Decoding Part */
    n = -n;
    z = v[n - 1];
    q = 6 + 52/n;
    sum = q*DELTA ;
    while (sum != 0) {
      e = (sum >> 2) & 3;
      for (p=n-1; p>0; p--) z = v[p-1], y = v[p] -= MX;
      z = v[n-1];
      y = v[0] -= MX;
      sum -= DELTA;
    }
    return 0;
  }
  return 1;
}

#define NITERS 3000
const byte flags[12][16] = {
  { 0xd0, 0x9a, 0xca, 0x37, 0xe9, 0x65, 0x86, 0x52, 0x50, 0xf8, 0xf3, 0xb3, 0x4f, 0x72, 0xc9, 0xad, },
  { 0x87, 0xd9, 0x22, 0x80, 0xaa, 0xd5, 0x7d, 0x25, 0x1a, 0x49, 0x82, 0x3b, 0x76, 0xa5, 0xbb, 0x17, },
  { 0x4c, 0xac, 0xd0, 0xf3, 0x76, 0xbd, 0xdf, 0xd8, 0x4d, 0x90, 0xc3, 0xa1, 0x0a, 0x07, 0xa7, 0xf4, },
  { 0x38, 0x96, 0xdd, 0xc4, 0xdd, 0x08, 0xe3, 0x60, 0xb2, 0xb2, 0x0a, 0x57, 0x06, 0x92, 0x58, 0xa2, },
  { 0x18, 0xd6, 0x0f, 0x7e, 0xc1, 0xb8, 0x52, 0xa1, 0xc5, 0x51, 0xe6, 0x6c, 0x52, 0x48, 0x28, 0xc5, },
  { 0x6e, 0xb6, 0xe0, 0xc3, 0x71, 0x22, 0xcd, 0x46, 0xd2, 0xc8, 0xd7, 0xe0, 0xfc, 0x81, 0x2f, 0x88, },
  { 0xf5, 0x49, 0x72, 0x81, 0xef, 0x2c, 0xec, 0x8c, 0x65, 0x98, 0xb4, 0x36, 0x01, 0xbf, 0xb2, 0x03, },
  { 0xa2, 0xa0, 0x3a, 0xe1, 0xbe, 0xce, 0x66, 0x42, 0x25, 0x51, 0x81, 0xed, 0x0b, 0xbe, 0x61, 0xac, },
  { 0x14, 0x71, 0x96, 0x90, 0x8a, 0x52, 0xd0, 0x6c, 0xa0, 0x8a, 0x00, 0x40, 0xab, 0xa8, 0xcf, 0x16, },
  { 0xe3, 0xc8, 0x36, 0x40, 0x53, 0x3e, 0xb1, 0xa7, 0x7a, 0x76, 0x93, 0xa4, 0xf2, 0x83, 0x29, 0x14, },
  { 0x3b, 0xbb, 0xd9, 0x9f, 0x99, 0x06, 0x42, 0x20, 0xd6, 0xbf, 0xfc, 0xfc, 0xe3, 0xb9, 0x6c, 0xc7, },
  { 0x61, 0x14, 0x09, 0x6a, 0x73, 0x9c, 0x94, 0x55, 0xf3, 0x3a, 0x75, 0x75, 0xd0, 0x1f, 0x0c, 0x79, },
};

const byte easterEggs[][16] = {
  { 0x7c, 0xfd, 0x7f, 0x9c, 0x96, 0x3f, 0x83, 0x42, 0x1e, 0x68, 0x02, 0xcd, 0x57, 0x04, 0xf4, 0x40, }, // matrix
  { 0x1a, 0x0a, 0x11, 0x68, 0x1d, 0x3b, 0x26, 0xb7, 0x6c, 0xa1, 0xfe, 0x57, 0xa4, 0x5b, 0xa1, 0xb9, }, // hack
  { 0x79, 0x30, 0x3b, 0xce, 0x1e, 0xea, 0xea, 0x4d, 0xac, 0xd1, 0x95, 0xf6, 0x60, 0x93, 0x15, 0x78, }, // 1337
  { 0xa6, 0x5f, 0xbd, 0xb0, 0xdb, 0xe1, 0x63, 0x11, 0xc7, 0x53, 0xd8, 0xed, 0xed, 0x37, 0xd8, 0x65, }, // cyber
  { 0x89, 0x02, 0x78, 0x20, 0x7e, 0x5a, 0x88, 0xcd, 0x04, 0xb9, 0xbc, 0xb8, 0xc1, 0xcf, 0xf6, 0x8e, }, // cyber2
  { 0xdb, 0x96, 0xea, 0xd8, 0xd3, 0xd3, 0xa5, 0xbe, 0x63, 0x49, 0x98, 0x7f, 0xdb, 0x01, 0xbf, 0x92, }, // wbm
  { 0x3a, 0xfa, 0x2d, 0x0c, 0x74, 0x52, 0xe6, 0xde, 0x5b, 0x1b, 0x6f, 0x14, 0x81, 0x50, 0xd8, 0xbb, }, // supersat
  { 0x63, 0x29, 0x74, 0x9f, 0x98, 0x81, 0xfe, 0xba, 0xd2, 0x5e, 0x71, 0x00, 0xb4, 0xb1, 0xc0, 0xc6, }, // jorge
  { 0x21, 0xfb, 0xc9, 0xf7, 0x53, 0x24, 0x22, 0x4e, 0xcb, 0x40, 0x38, 0xb4, 0x66, 0x7d, 0xc7, 0x88, }, // gibson
  { 0x24, 0x32, 0x1c, 0x25, 0xc7, 0x43, 0x01, 0x43, 0x48, 0xe5, 0x79, 0x8e, 0xea, 0x2b, 0xa1, 0xaa, }, // acidburn
  { 0xfd, 0x50, 0xe4, 0xbc, 0xba, 0x76, 0xb2, 0xb7, 0xc9, 0x42, 0xb0, 0x2d, 0x88, 0x05, 0x68, 0x2b, }, // zerocool
  { 0xa9, 0xa4, 0x3f, 0xd2, 0x99, 0x6e, 0x5e, 0xe6, 0x90, 0x32, 0x5d, 0xcf, 0xbf, 0xef, 0xea, 0x9c, }, // joegrand
  { 0x04, 0x66, 0x67, 0xc1, 0xde, 0x29, 0xa6, 0x4a, 0xf5, 0x22, 0x76, 0x6d, 0xa6, 0x23, 0x9f, 0x72, }, // jeffmoss
  { 0xdd, 0xed, 0x3f, 0xd0, 0x3b, 0x28, 0x40, 0xff, 0x9a, 0x6a, 0x78, 0x14, 0x8f, 0xd2, 0xb0, 0xa4, }, // travis
  { 0x8d, 0x51, 0x54, 0xcf, 0xd6, 0xb2, 0x4c, 0xea, 0xe4, 0x37, 0xf2, 0x4d, 0x4b, 0xed, 0x10, 0xc7, }, // ossmann
  { 0x9e, 0x55, 0x9a, 0xfe, 0x68, 0x49, 0xaa, 0x81, 0x3d, 0x0a, 0xfa, 0x7c, 0x5f, 0xcd, 0x6d, 0xe5, }, // gmark  
  { 0x27, 0x8e, 0x28, 0xcb, 0x64, 0xa6, 0xc2, 0xeb, 0x1a, 0xa8, 0xee, 0x2c, 0x53, 0x4b, 0x95, 0x5e, }, // nsa
  { 0xef, 0xd4, 0x53, 0xf8, 0xfe, 0x44, 0x18, 0x0c, 0xf5, 0x85, 0xae, 0x3e, 0xbe, 0x2a, 0xa6, 0xd7, }, // goon
  { 0x95, 0x2e, 0x77, 0xed, 0x8d, 0xd9, 0x93, 0x9a, 0x87, 0x03, 0x6f, 0x70, 0x7c, 0x3a, 0xb9, 0x74, }, // beer
  { 0x9f, 0x03, 0x74, 0x48, 0xf6, 0x14, 0x6a, 0x3f, 0xd5, 0x71, 0x32, 0x22, 0x0a, 0xc3, 0x06, 0x3a, }, // had
  { 0xf2, 0x0d, 0x2b, 0x37, 0xf6, 0x52, 0xea, 0xe1, 0x1e, 0xd4, 0x16, 0x16, 0xc8, 0xe7, 0x02, 0xf2, }, // ninja
  { 0x6d, 0x28, 0x5a, 0xbb, 0x2e, 0x19, 0x8e, 0xff, 0x01, 0x51, 0x4d, 0x49, 0x3e, 0x7c, 0x9d, 0xdc, }, // neon
  { 0x24, 0x5c, 0x97, 0x45, 0x0c, 0xcc, 0x64, 0xc4, 0x54, 0x2a, 0x11, 0x3a, 0xff, 0x79, 0x95, 0x99, }, // diffie
  { 0xdc, 0x57, 0x77, 0x64, 0xee, 0x87, 0x4c, 0xd6, 0x64, 0x30, 0x06, 0x57, 0x79, 0x6c, 0x4b, 0x33, }, // hellman
  { 0xf6, 0x54, 0x5a, 0x0f, 0xac, 0x5e, 0x98, 0x19, 0x2b, 0x2b, 0xcd, 0x84, 0x33, 0xa4, 0x58, 0x85, }, // 1057
  { 0x14, 0xf7, 0x67, 0xfd, 0x6b, 0xc6, 0x5b, 0x26, 0xbd, 0x6c, 0xe1, 0xc4, 0x38, 0x5e, 0xc3, 0xb7, }, // knight
  { 0x6f, 0xea, 0x66, 0x53, 0x2d, 0x7f, 0xcf, 0x15, 0x88, 0xc6, 0xfa, 0xfe, 0x65, 0xd1, 0x09, 0x7f, }, // fuck
  { 0xf4, 0x00, 0x35, 0x86, 0x51, 0x9e, 0x86, 0xa7, 0xf1, 0x71, 0x46, 0x5e, 0xb3, 0xc9, 0xdc, 0xb3, }, // defcon
  { 0xeb, 0x0c, 0xe6, 0xb4, 0x10, 0x6b, 0x00, 0xd8, 0x93, 0xd5, 0xdc, 0x54, 0x14, 0x6f, 0xeb, 0xbc, }, // defcoin
  { 0xd8, 0x09, 0x9d, 0xa3, 0x72, 0x29, 0x09, 0xe9, 0x07, 0x4e, 0x63, 0x73, 0xf9, 0x17, 0x67, 0xf1, }, // alice
  { 0x79, 0x42, 0x59, 0x82, 0xae, 0x36, 0x66, 0xec, 0x7d, 0xb4, 0x63, 0x65, 0x34, 0x58, 0x1b, 0xc8, }, // bob
  { 0x68, 0xf6, 0xda, 0xdf, 0x75, 0x86, 0x4d, 0xb5, 0x4d, 0x3e, 0x0f, 0x39, 0xc6, 0xb2, 0xba, 0x63, }, // eve
  { 0x74, 0x08, 0x80, 0xde, 0x32, 0x38, 0xc4, 0x25, 0x54, 0x5f, 0xb2, 0x98, 0x17, 0xf8, 0x3a, 0xeb, }, // eff
  { 0x86, 0x31, 0x5f, 0xfd, 0x63, 0x18, 0xec, 0x9b, 0xb6, 0x34, 0xb8, 0xe8, 0xbc, 0xd1, 0x9e, 0xf2, }, // rot13
  { 0xc2, 0x2c, 0xcf, 0x64, 0x51, 0xb5, 0x19, 0x70, 0x34, 0x4b, 0xdd, 0x8c, 0x04, 0x14, 0x6e, 0x44, }, // openssl
  { 0xe7, 0xcc, 0xd8, 0x45, 0xd7, 0x68, 0x7b, 0x9e, 0x10, 0xd2, 0x38, 0xa5, 0xcd, 0x0b, 0xd6, 0x65, }, // darthnul
  { 0x01, 0x98, 0x03, 0x88, 0xa7, 0x18, 0x1a, 0xd5, 0xb3, 0xac, 0x49, 0x6f, 0xa3, 0xcd, 0xd5, 0x38, }, // wargames
  { 0x38, 0xb9, 0xb0, 0x31, 0x58, 0xc5, 0xf2, 0xcd, 0xd8, 0xeb, 0x1c, 0xe9, 0xaf, 0x0c, 0x06, 0x4a, }, // thenet
  { 0xec, 0xbc, 0x28, 0xa0, 0x2f, 0xc6, 0x94, 0x57, 0xf3, 0x4b, 0x36, 0xd1, 0x6c, 0xe7, 0x96, 0xa7, }, // sneakers
  { 0xf6, 0x76, 0x25, 0xde, 0xf6, 0x2c, 0xbf, 0x81, 0xcf, 0x27, 0x1a, 0x7b, 0xa7, 0x4d, 0x90, 0xd8, }, // setec
  { 0x86, 0x99, 0x6f, 0x3b, 0x5f, 0x54, 0x90, 0x47, 0xaa, 0xb3, 0xa3, 0x20, 0xca, 0xa0, 0x30, 0xc6, }, // lotr
  { 0xb9, 0xcf, 0xf5, 0x7d, 0x47, 0x93, 0xce, 0xa8, 0xe1, 0x28, 0xd6, 0x3e, 0xd2, 0x8a, 0x13, 0xc8, }, // led1
  { 0xfd, 0x4f, 0x52, 0x4a, 0x58, 0x2a, 0xe1, 0xab, 0xed, 0x68, 0x40, 0x9f, 0x12, 0x35, 0xfa, 0xec, }, // led2
  { 0x2f, 0x5d, 0x1c, 0x8b, 0x36, 0xe4, 0xfa, 0x0f, 0x4e, 0xd4, 0x7d, 0x2d, 0xd8, 0x2e, 0xa4, 0x35, }, // pong
  { 0xab, 0xf1, 0xfd, 0x22, 0x8f, 0xc6, 0xa6, 0x43, 0xd6, 0xfa, 0x70, 0xce, 0x2f, 0x22, 0x22, 0x54, }, // party
  { 0x44, 0xf1, 0x00, 0xfc, 0xc6, 0x78, 0x40, 0xd3, 0x0d, 0x02, 0x89, 0xac, 0x45, 0xfc, 0x75, 0x01, }, // rager
  { 0xaa, 0x8f, 0x49, 0xe3, 0x8f, 0x28, 0x31, 0xbd, 0xb5, 0x31, 0xb4, 0x10, 0x03, 0xc6, 0x37, 0x80, }, // scorpion
  { 0xe9, 0xab, 0x4d, 0x4c, 0x12, 0x59, 0x91, 0x44, 0xef, 0xc7, 0x91, 0x2b, 0xf5, 0xd4, 0xc9, 0xe9, }, // 3ffd0n0r
  { 0x64, 0xe8, 0x8b, 0xba, 0xf0, 0x30, 0x48, 0x65, 0x61, 0x08, 0x8f, 0xcf, 0x0c, 0x70, 0x25, 0xd9, }, // tetris
  { 0xf8, 0x7d, 0x71, 0x0e, 0xbd, 0xfd, 0x2d, 0x3b, 0x67, 0xa8, 0x0a, 0x46, 0xf5, 0xbd, 0xd0, 0x6c, }, // overclok
  { 0xdf, 0x15, 0x65, 0xfd, 0xa4, 0xb6, 0x3a, 0x06, 0xbb, 0x9f, 0x8a, 0xc9, 0x73, 0xfb, 0x10, 0x05, }, // bulletym
  { 0xe7, 0xd2, 0x8a, 0x60, 0xdb, 0x2d, 0x63, 0x01, 0x41, 0x82, 0xc6, 0xb4, 0x3e, 0x31, 0xb6, 0xd0, }, // factoryr
  { 0xb2, 0x85, 0xd7, 0x06, 0x90, 0x91, 0x58, 0x01, 0x43, 0xa4, 0x46, 0x29, 0x69, 0xd6, 0xda, 0xd2, }, // sse
  { 0x08, 0xca, 0x0a, 0x23, 0xf8, 0x15, 0x28, 0x13, 0x4f, 0xce, 0x35, 0xb1, 0x97, 0xec, 0xe9, 0xc8, }, // sorry
  { 0xa6, 0xe0, 0xaa, 0xa1, 0x5f, 0x48, 0x30, 0x80, 0x93, 0x49, 0x23, 0x8d, 0xf8, 0xa5, 0x6c, 0xbd, }, // count
};
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
void loop()
{
  // TODO: Make this interrupt-based to save power
  updateButtonStatus();
  switch (badgeState) {
  case SELF_TEST_MODE:
    selfTestMode();
    break;
  case DISPLAY_MODE:
    displayMode();
    break;
  case FLAG_ENTRY_MODE:
    flagEntryMode();
    break;
  case FLAG_OBTAINED_MODE:
    flagObtainedMode();
    break;
  case FLAG_FAIL_MODE:
    flagFailMode();
    break;
  case SCROLL_MODE:
    scrollMode();
    break;
  case PARTY_CONFIRM_MODE:
    partyConfirmMode();
    break;
  case PARTY_MODE:
    partyMode();
    break;
  case SSE_MODE:
    sseMode();
    break;
  case SHOW_FLAG_MODE:
    showFlagMode();
    break;
  default:
    strncpy(dispBuf, "  help  ", 8);  
    break;
  }
  
  refreshDisplay();
  if (tempModeFlag & TEMP_MODE_FLAG_BULLET_TIME) {
    sleep(20);
  } else {
    __delay_cycles(5000);  
  }
}
